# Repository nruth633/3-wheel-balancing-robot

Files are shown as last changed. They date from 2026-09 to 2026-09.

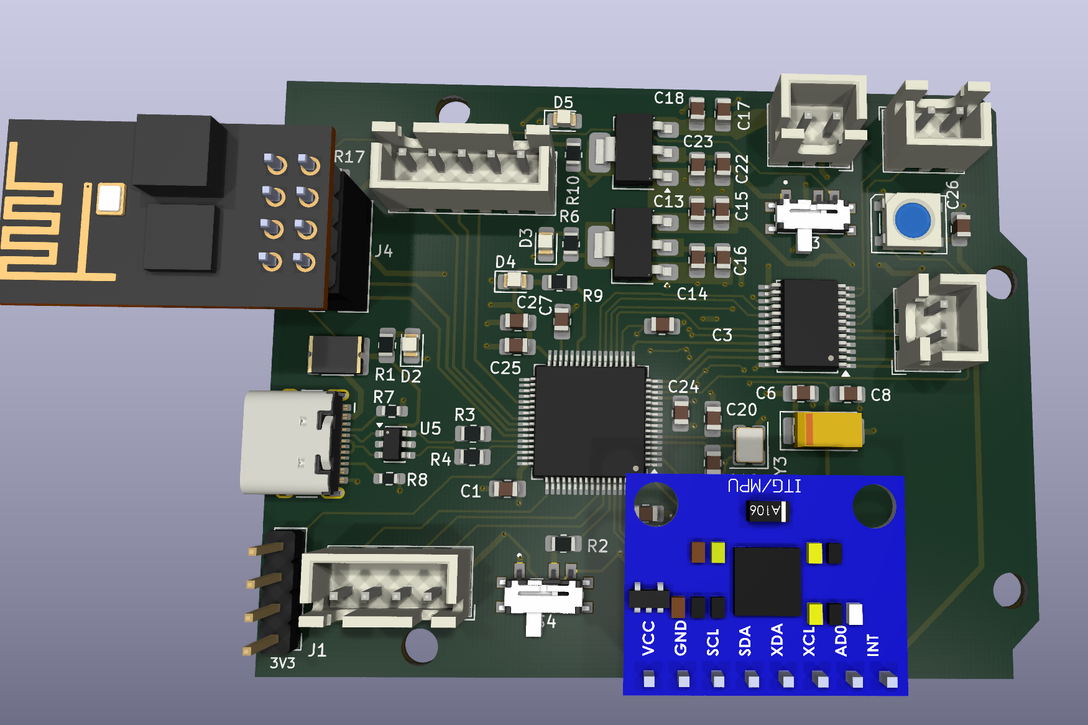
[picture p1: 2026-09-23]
firmware_main/Docs_Process/3D.png

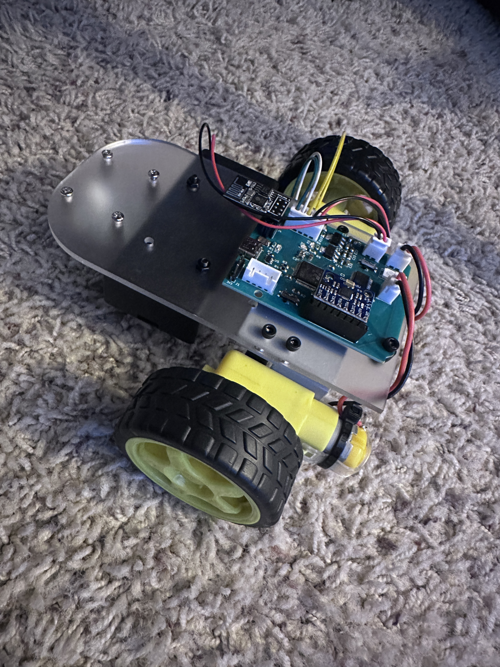
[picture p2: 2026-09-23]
firmware_main/Docs_Process/ROBOT_TOP.JPG

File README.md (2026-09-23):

# 3-Wheel Robot

A three-wheel robot on an STM32F401 control board I designed in KiCad and soldered by hand.
An ESP8266 runs its own WiFi access point and serves a control page, so you can drive it from
a phone browser. Button presses go over a WebSocket to the ESP8266, which passes them to the
STM32 over UART. Roll and pitch from the MPU6050 are sent back to the page. The STM32 firmware was provided
by my professor; I built it and flashed the board with STM32CubeIDE and STM32CubeProgrammer.

I started this as a self-balancing robot, but I didn't get as far as a working balance
controller, so for now it only drives. The wheel encoder code is also switched off, so the
speed readout on the control page stays at 0.

Write-up: https://nruth633.github.io/projects/balancing-robot.html

## What's in here

- `balance_noEncoder/`: the STM32 firmware (STM32CubeIDE, HAL). Reads the MPU6050 through a
  complementary filter at 100 Hz, drives the motors through a TB6612FNG, and talks to the
  ESP8266 over UART.
- `remote_esp8266/`: the ESP8266 sketch (access point, web page, WebSocket server).
- `pcb/`: KiCad project for the control board.
- `firmware_v2/`: KiCad project for a later board revision.
- `firmware_main/`: the first board, a two-wheel version: KiCad files, gerbers, an
  interactive BOM, a CAD model of the assembly, and build photos. No firmware, despite
  the name.

The board files were saved in KiCad 9 and 10, so open them in KiCad 10.

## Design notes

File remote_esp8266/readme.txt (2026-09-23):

Example 1 and 2
*********************
- Reference/intermediate code used to build ESP8266_KitchenTimer

ESP8266_KitchenTimer
*********************
- HTML being used inside ESP
- Open file and compress it using this link -> https://www.textfixer.com/html/compress-html-compression.php
- Copy the compress version and paste inside the message string arduino code.

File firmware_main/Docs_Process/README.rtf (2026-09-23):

-The PCB schematic and layout were designed in Kicad.
-Once manufactured I hand soldered the SMD components to the board and tested.
-The PCB was measured in Onshape so I could design a base
-The acrylic base was first drawn out in Onshape, printed on paper to ensure the parts would fit, and then it was sent to the CO2 laser cutter for manufacturing.
-Once the base was made, the PCB, batteries, motors, encoder, and wheels were attached to the base.
-The STM32 program provided by our professor, I used STM32CubeIDE and STM32CubeProgrammer to build, and flash the PCB.
-Once the program was on the board I tested it by connecting my phone to the ESP8266, and go to the ip address in a browser.
-Upon testing the robot works as intended. One issue I noticed was the ESP8266 app would sometimes disconnect, but would reconnect a few moments later.

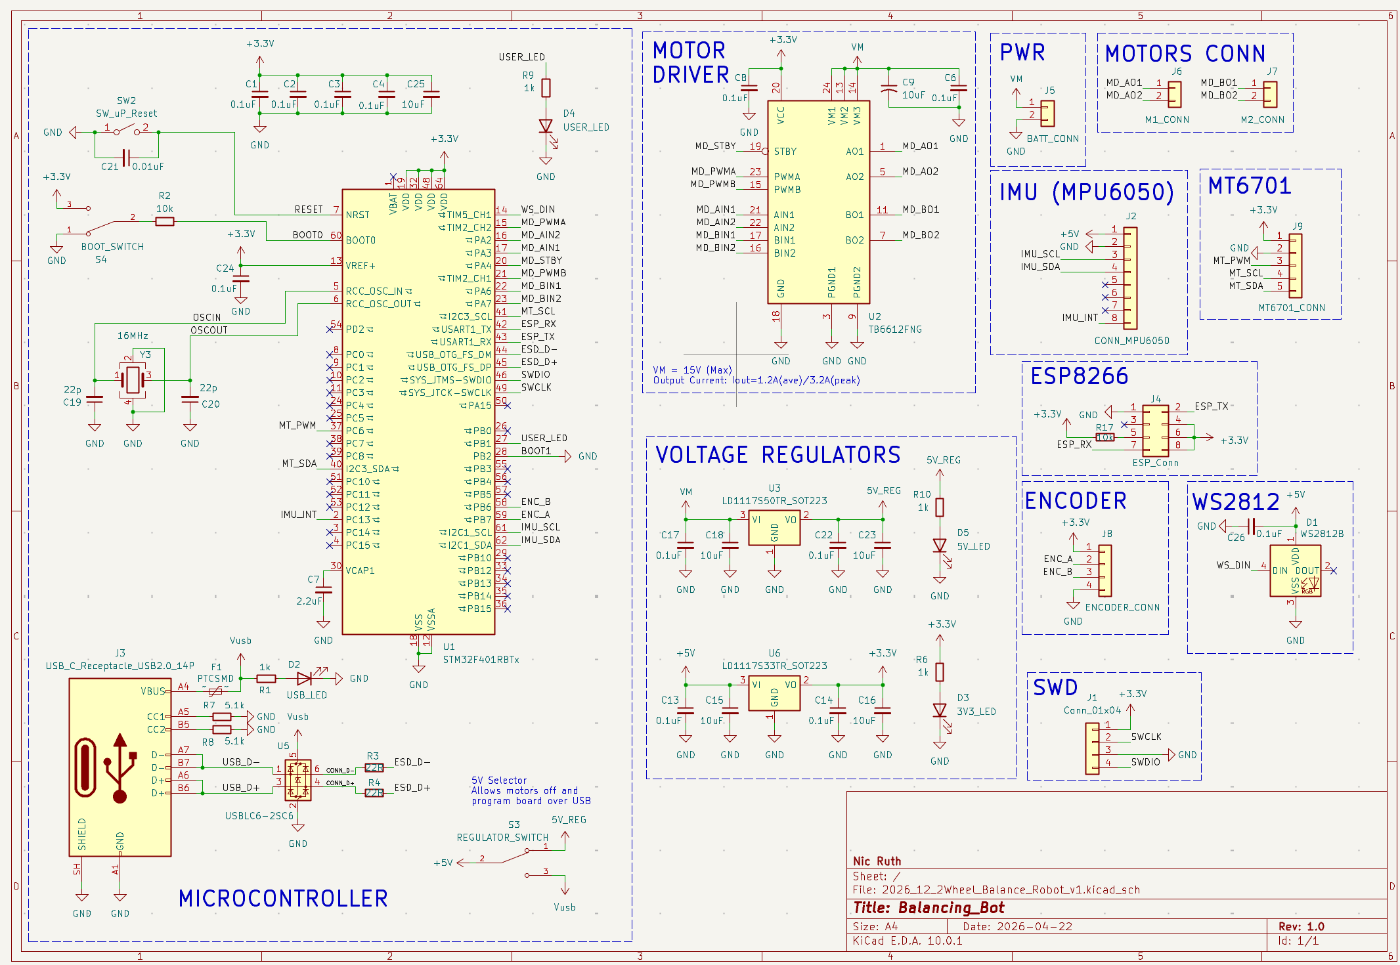
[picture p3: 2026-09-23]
firmware_main/Docs_Process/SCHEMATIC.png

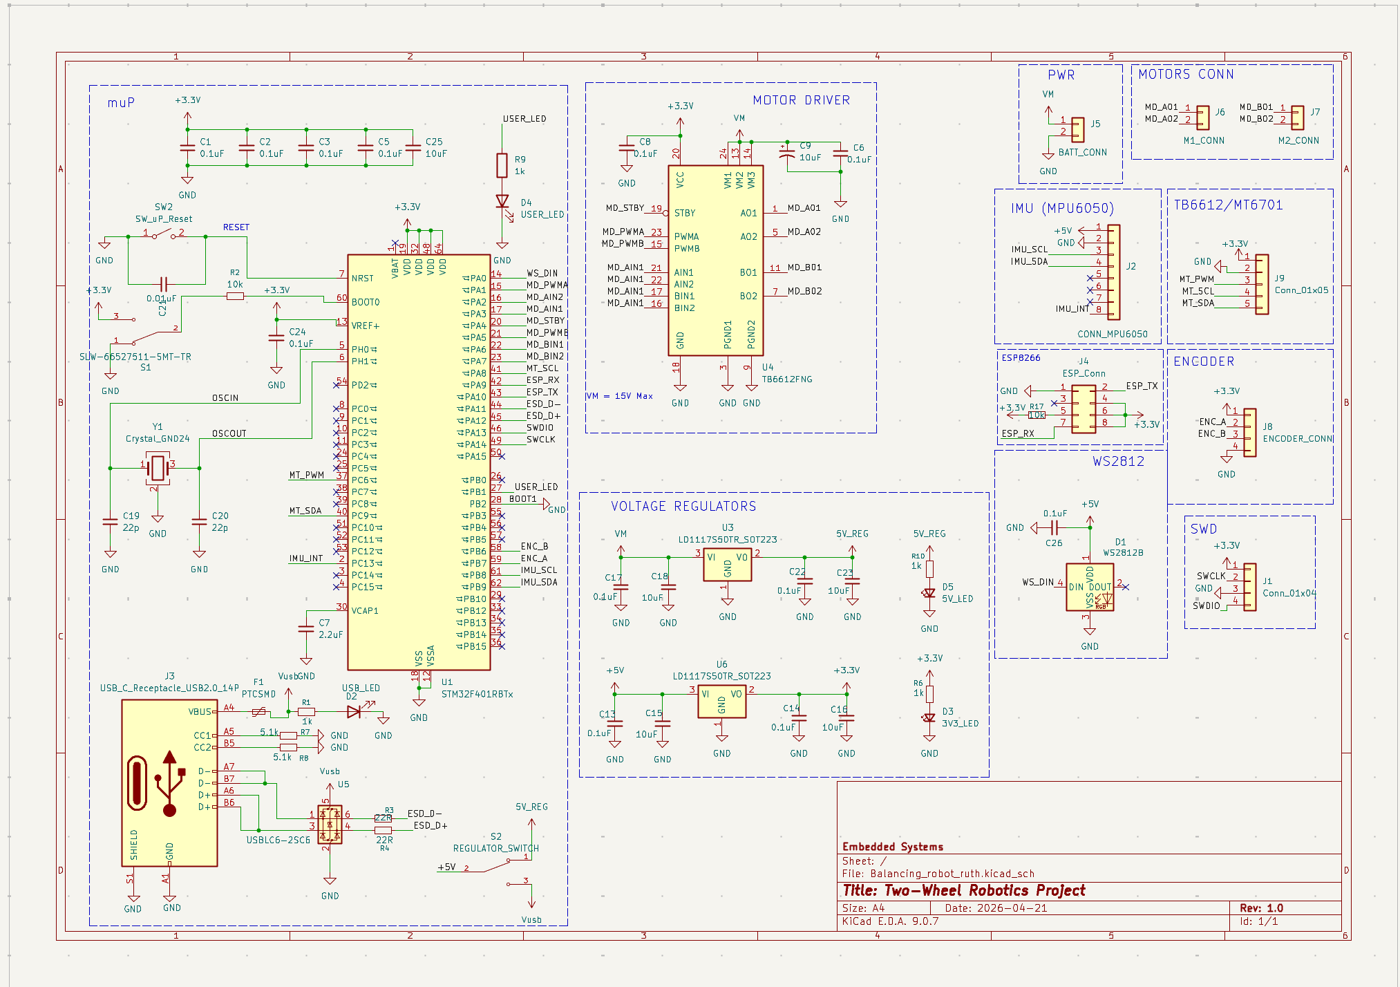
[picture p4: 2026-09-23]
pcb/docs/SCHEM.png

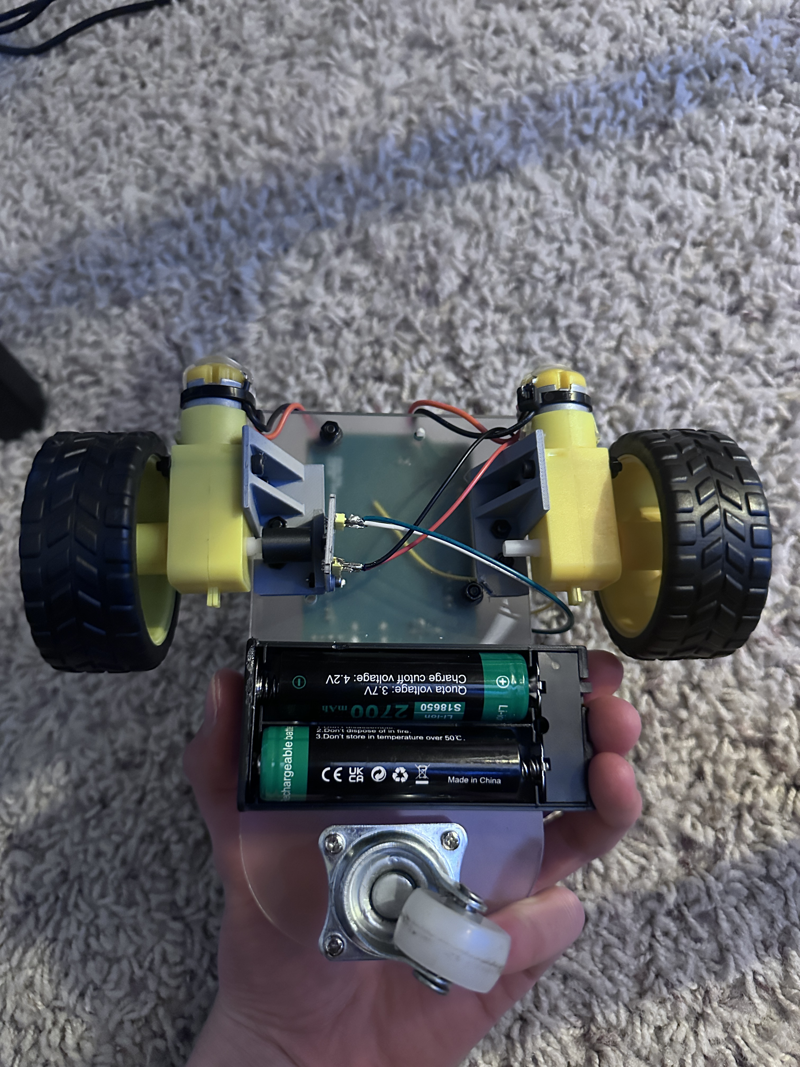
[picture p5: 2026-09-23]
firmware_main/Docs_Process/ROBOT_BOTTOM.JPG

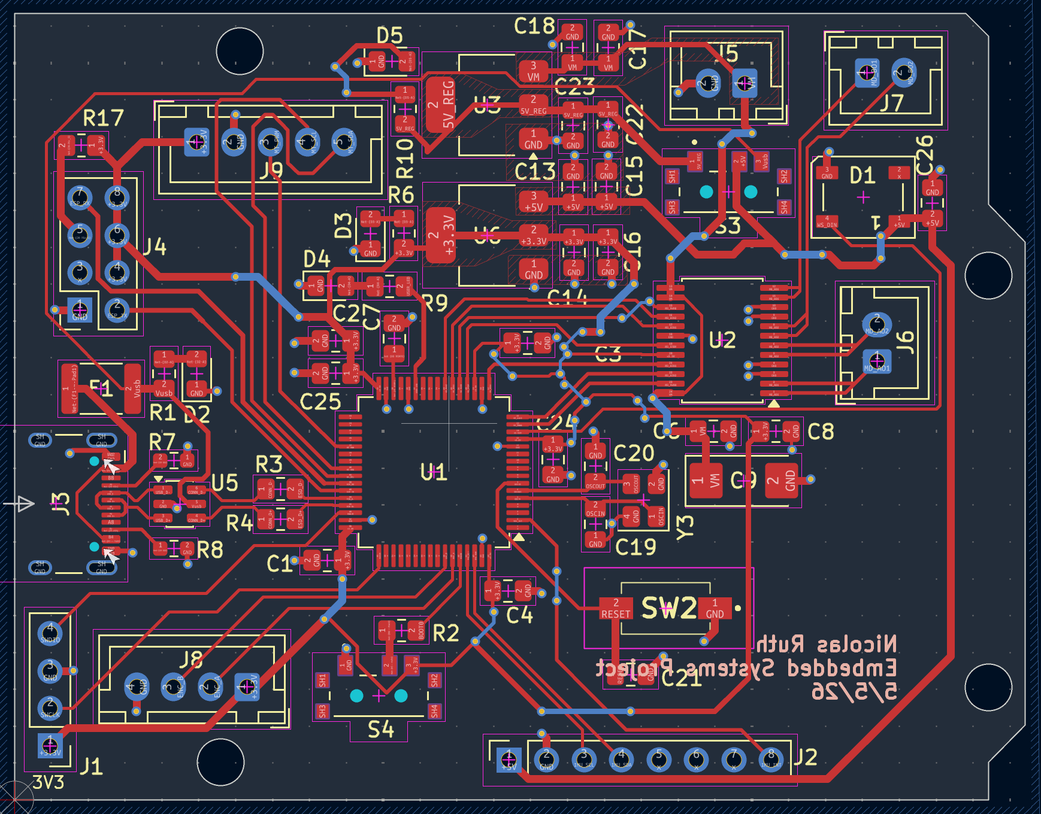
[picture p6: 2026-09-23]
firmware_main/Docs_Process/LAYOUT.png

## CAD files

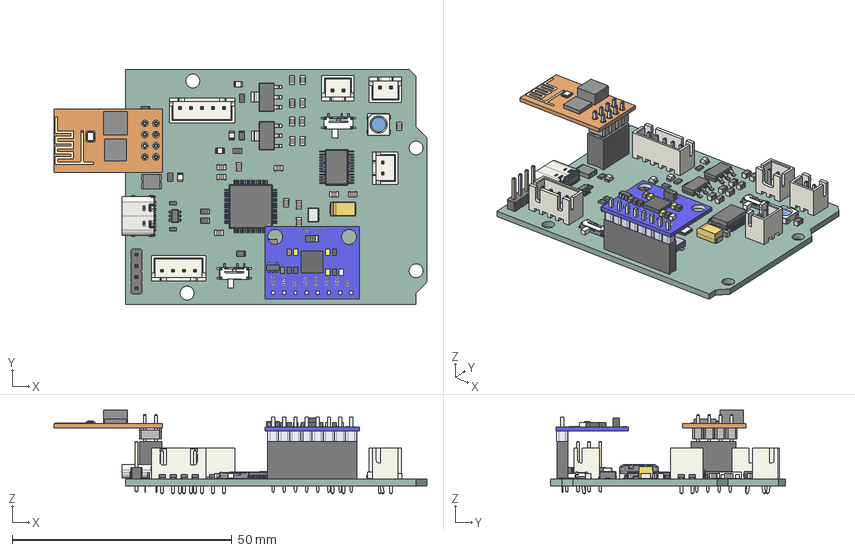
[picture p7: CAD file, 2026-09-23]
firmware_main/cad/robot_assembly.step
84.9 x 53.4 x 19.0 mm
C_0805_2012Metric x 21
MF-MSMF050-2--3DModel-STEP-56544
R_0805_2012Metric x 8
SOT-23-6
SOT-223 x 2
SLW-66527511-SMT-TR x 2
PinSocket_2x04_P2.54mm_Vertical
ESP8266-01_ESP-01
R_0603_1608Metric x 2
SSOP-24_5.3x8.2mm_P0.65mm
LED_WS2812B_PLCC4_5.0x5.0mm_P3.2mm
base
top cover
pins x 2
LQFP-64_10x10mm_P0.5mm
LED_0805_2012Metric x 4
Crystal_SMD_Abracon_ABM8G-4Pin_3.2x2.5mm
JST_XH_B2B-XH-A_1x02_P2.50mm_Vertical x 3
PinHeader_1x04_P2.54mm_Vertical
JST_XH_B5B-XH-A_1x05_P2.50mm_Vertical
USB_C_Receptacle_GCT_USB4105-xx-A_16P_TopMnt_Horizontal
PinSocket_1x08_P2.54mm_Vertical
8 Header-Pin
Placa_Base
CP_EIA-6032-28_Kemet-C
JST_XH_B4B-XH-A_1x04_P2.50mm_Vertical
2026_12_2Wheel_Balance_Robot_v1_PCB

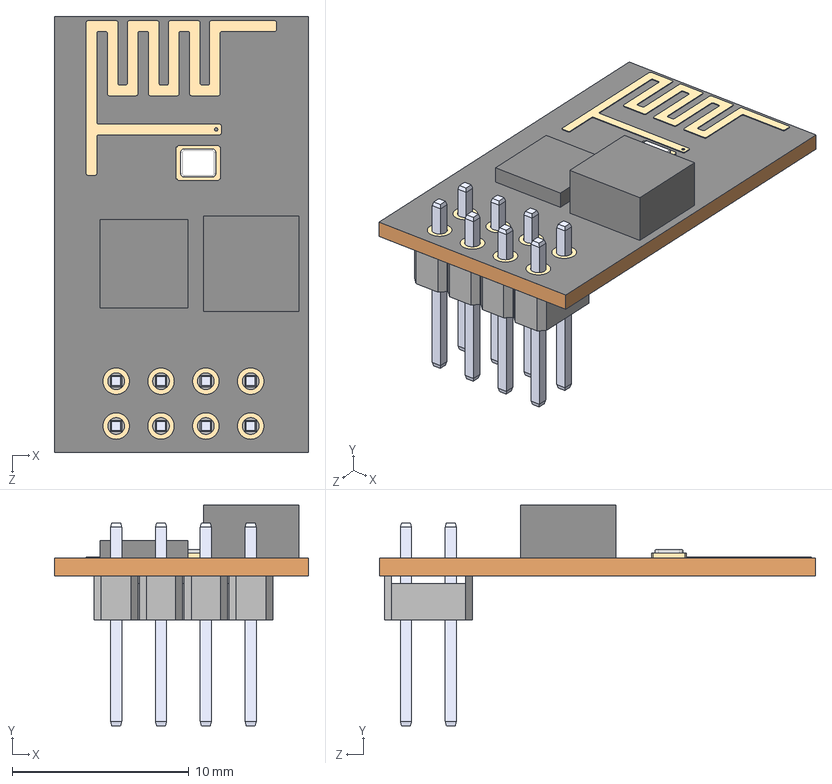
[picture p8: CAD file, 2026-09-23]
firmware_main/Components/ESP8266-01_ESP-01/step/ESP8266-01_ESP-01.step
14.4 x 12.5 x 24.7 mm

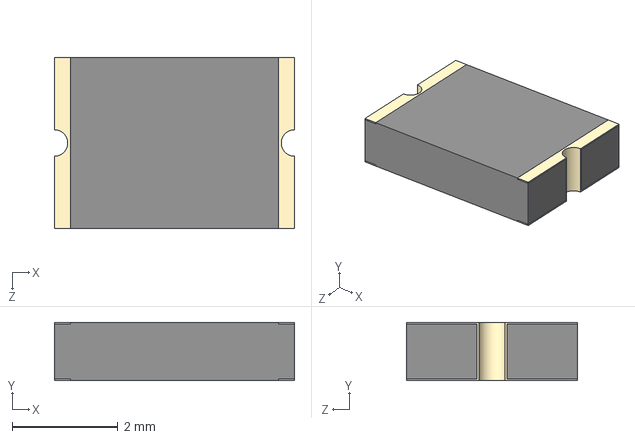
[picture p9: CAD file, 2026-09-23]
firmware_main/Components/Fuse_3DModel/MF-MSMF050-2--3DModel-STEP-56544.STEP
4.55 x 1.10 x 3.24 mm

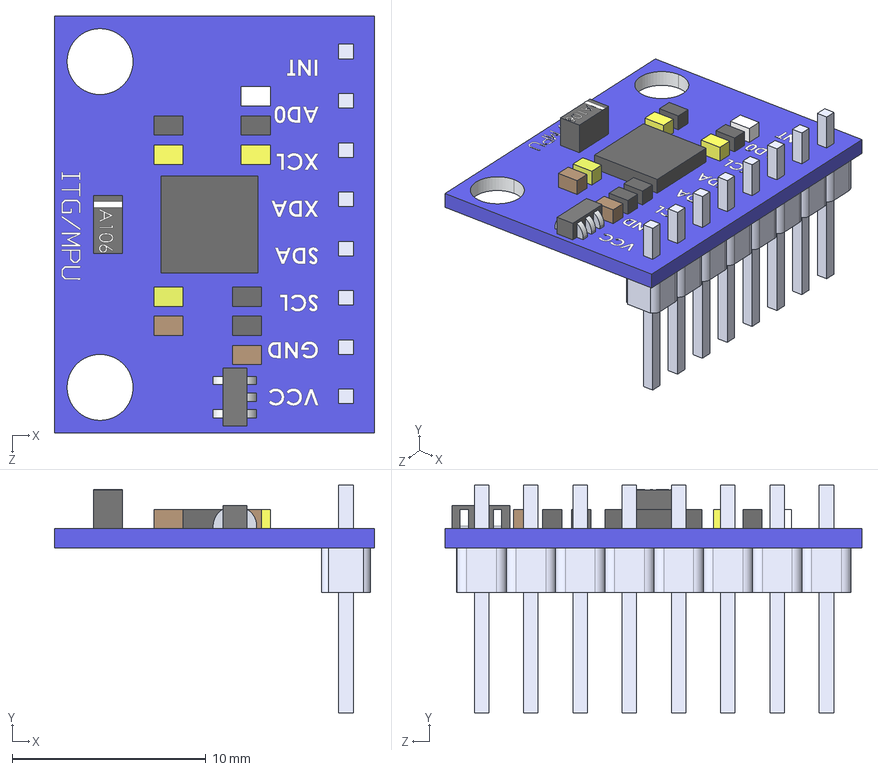
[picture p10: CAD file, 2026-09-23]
firmware_main/Components/MPU6050/ITG-MPU.STEP
16.5 x 11.8 x 21.5 mm
8 Header-Pin
Placa_Base

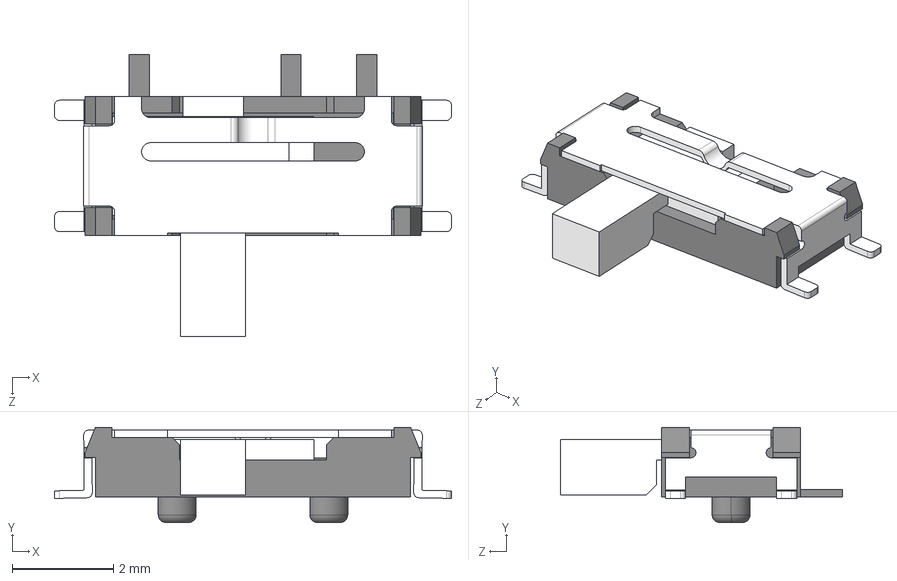
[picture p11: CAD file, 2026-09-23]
firmware_main/Components/SPDT_Slide_Switch/step/SLW-66527511-SMT-TR.step
7.86 x 1.88 x 5.58 mm

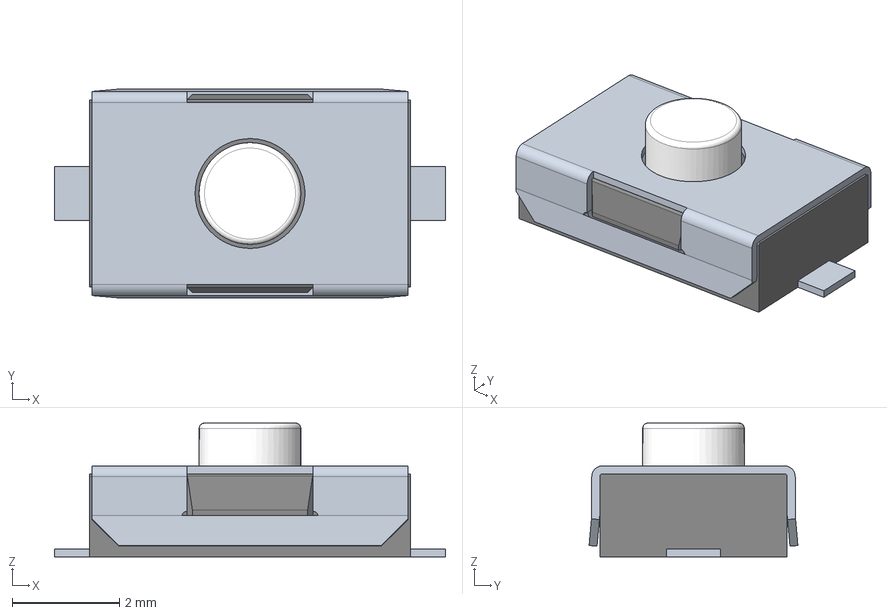
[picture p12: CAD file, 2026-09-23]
firmware_main/Components/SW_uP_Reset/step/SW_uP_Reset.stp
7.30 x 3.90 x 2.50 mm

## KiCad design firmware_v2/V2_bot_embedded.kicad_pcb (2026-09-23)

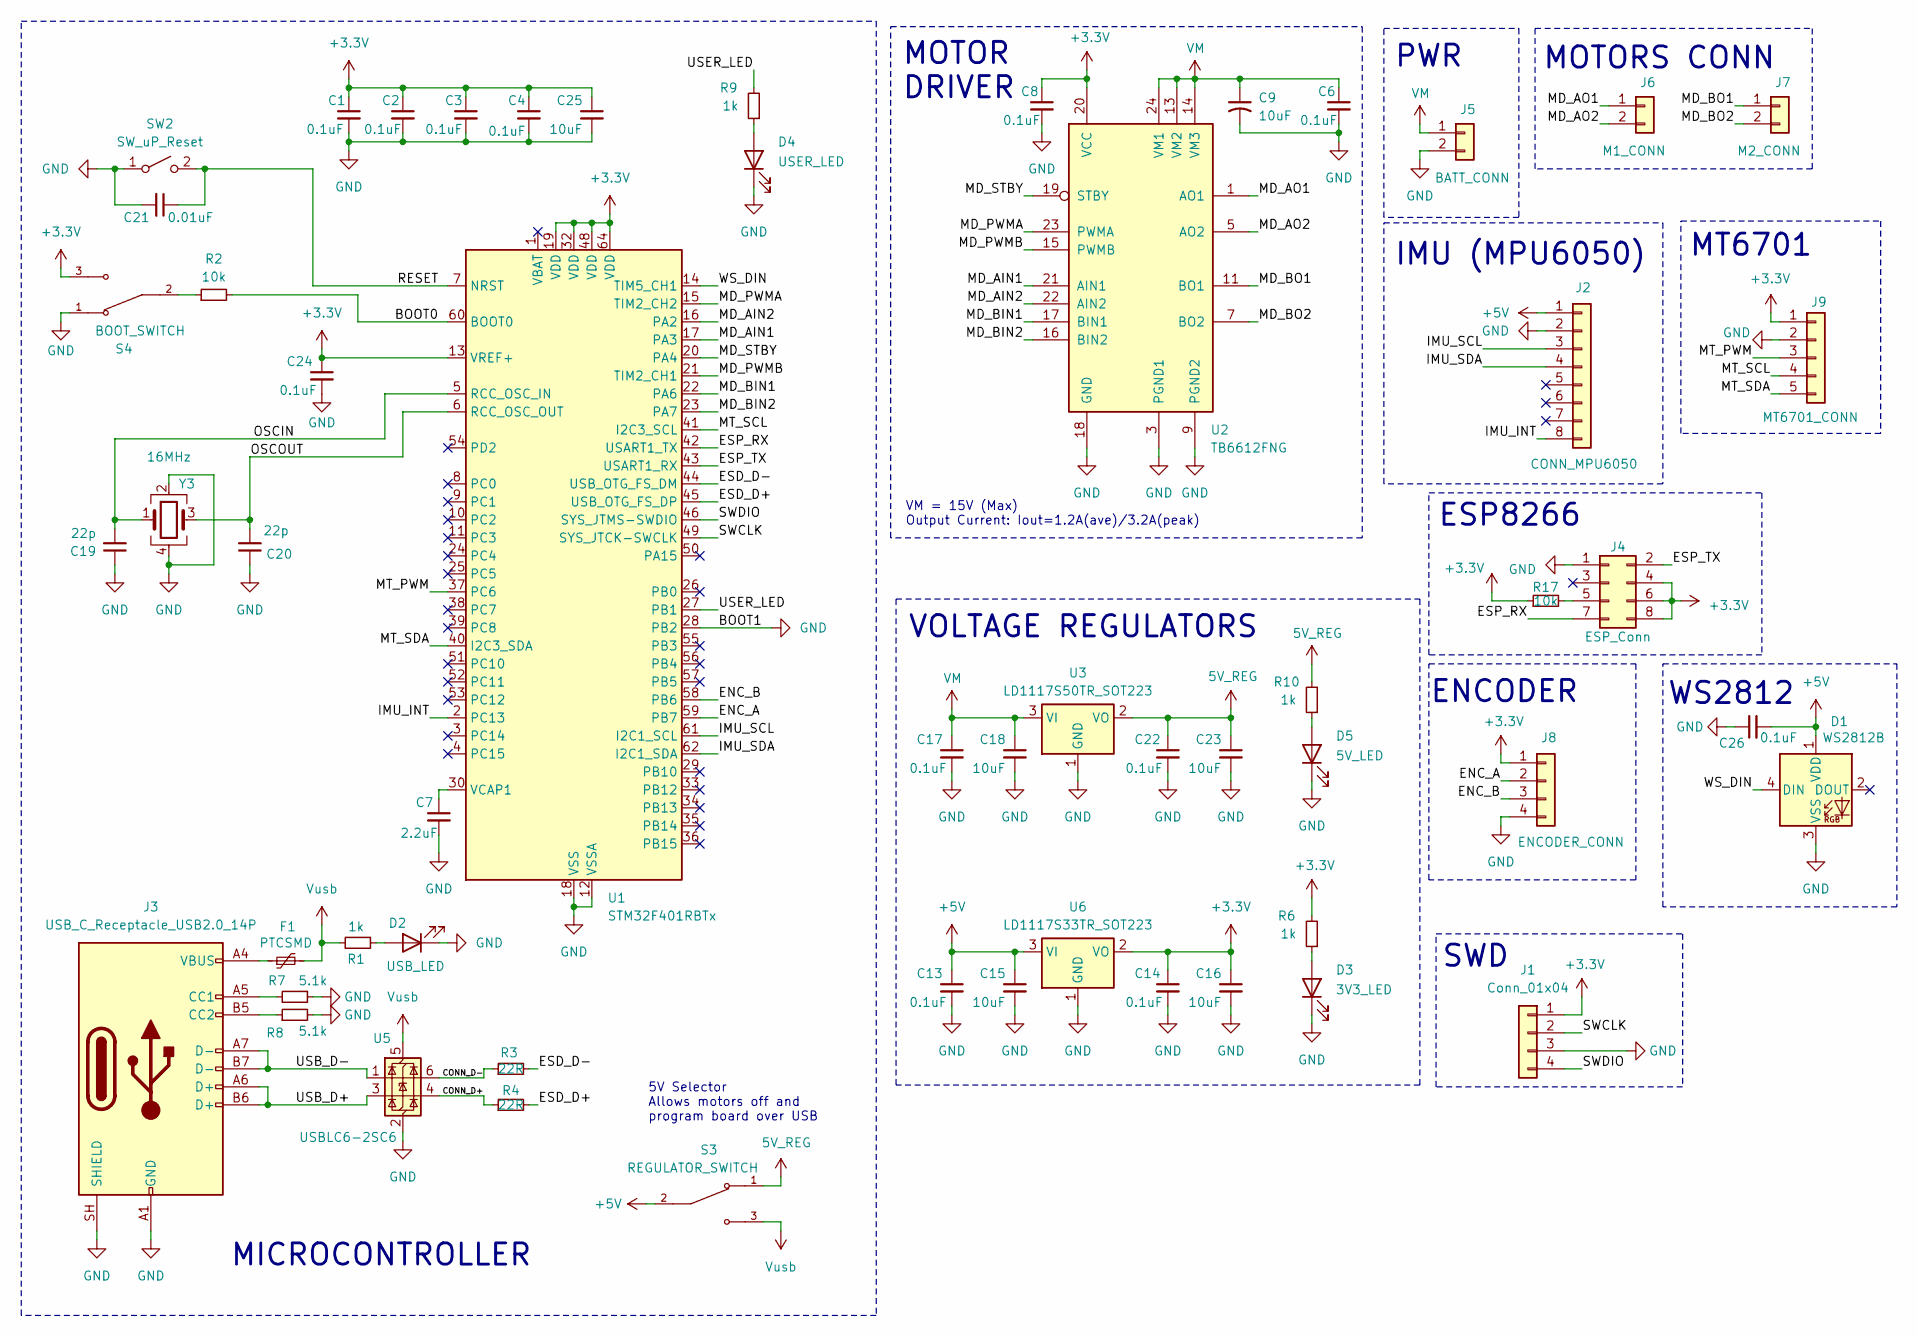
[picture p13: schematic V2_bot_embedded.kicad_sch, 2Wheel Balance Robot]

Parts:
C1, C2, C3, C4, C6, C8, C13, C14, C17, C22, C24, C26: 0.1uF; C_0805_2012Metric_Pad1.18x1.45mm_HandSolder; Mfr # C0805C104K4JACAUTO
C7: 2.2uF; C_0805_2012Metric_Pad1.18x1.45mm_HandSolder; Mfr # C0805X225K3RACAUTO
C9: 10uF; CP_EIA-6032-28_Kemet-C_HandSolder; Mfr # TPSC106M025R0500
C15, C16, C18, C23: 10uF; C_0805_2012Metric_Pad1.18x1.45mm_HandSolder; Mfr # C0805C106K4PACTU
C19, C20: 22p; C_0805_2012Metric_Pad1.18x1.45mm_HandSolder; Mfg Part# 08055C220KAT2A
C21: 0.01uF; C_0805_2012Metric_Pad1.18x1.45mm_HandSolder; Mfg Part# KAF21BR72A103JT
C25: 10uF; C_0805_2012Metric_Pad1.18x1.45mm_HandSolder; Mfg Part# C0805C106K4PACTU
D1: WS2812B; LED_WS2812B_PLCC4_5.0x5.0mm_P3.2mm; Mfr # FZ2812-5050; Mouser Digikey Part
D2: USB_LED; LED_0805_2012Metric_Pad1.15x1.40mm_HandSolder; Mfr # 150080BS75000
D3: 3V3_LED; LED_0805_2012Metric_Pad1.15x1.40mm_HandSolder; Mfr # 150080BS75000
D4: USER_LED; LED_0805_2012Metric_Pad1.15x1.40mm_HandSolder; Mfr # 150080BS75000
D5: 5V_LED; LED_0805_2012Metric_Pad1.15x1.40mm_HandSolder; Mfr # 150080BS75000
F1: PTCSMD; Fuse_1812_4532Metric; Mfr # MF-MSMF050-2
J1: Conn_01x04; PinHeader_1x04_P2.54mm_Vertical
J2: CONN_MPU6050; PinSocket_1x08_P2.54mm_Vertical
J3: USB_C_Receptacle_USB2.0_14P; USB_C_Receptacle_HCTL_HC-TYPE-C-16P-01A; Mfg Part# UJ20-C-H-C-4-SMT-TR
J4: ESP_Conn; PinSocket_2x04_P2.54mm_Vertical
J5: BATT_CONN; JST_XH_B2B-XH-A_1x02_P2.50mm_Vertical
J6: M1_CONN; JST_XH_B2B-XH-A_1x02_P2.50mm_Vertical
J7: M2_CONN; JST_XH_B2B-XH-A_1x02_P2.50mm_Vertical
J8: ENCODER_CONN; JST_XH_B4B-XH-A_1x04_P2.50mm_Vertical
J9: MT6701_CONN; JST_XH_B5B-XH-A_1x05_P2.50mm_Vertical
R1, R6, R9, R10: 1k; R_0805_2012Metric_Pad1.20x1.40mm_HandSolder; Mfr # TNPW08051K00FEEA
R2, R17: 10k; R_0805_2012Metric_Pad1.20x1.40mm_HandSolder; Mfr # CPF0805B10KE1
R3, R4: 22R; R_0805_2012Metric_Pad1.20x1.40mm_HandSolder; Mfr # RCA080522R0FKEA
R7, R8: 5.1k; R_0603_1608Metric_Pad0.98x0.95mm_HandSolder; Mfg Part# CRCW06035K10FKEC
S3: REGULATOR_SWITCH; SW_SLW-66527511-SMT-TR; PARTREV 1.01
S4: BOOT_SWITCH; SW_SLW-66527511-SMT-TR; PARTREV 1.01
SW2: SW_uP_Reset; Mfg Part# 434121025816
U1: STM32F401RBTx; LQFP-64_10x10mm_P0.5mm; Mfr # STM32F401RBT6
U2: TB6612FNG; SSOP-24_5.3x8.2mm_P0.65mm; Mfr # TB6612FNG,C,8,EL
U3: LD1117S50TR_SOT223; SOT-223-3_TabPin2; Mfr # LD1117S50TR
U5: USBLC6-2SC6; SOT-23-6; Mfr # USBLC6-2SC6
U6: LD1117S33TR_SOT223; SOT-223-3_TabPin2; Mfr # LD1117S33TR
Y3: 16MHz; Crystal_SMD_Abracon_ABM8G-4Pin_3.2x2.5mm; Mfg Part# ABM8-16.000MHZ-D1X-T

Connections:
5V_REG: C22.1, C23.1, R10.2, S3.1, U3.2 (VO)
+3.3V: C1.1, C2.1, C3.1, C4.1, C8.1, C14.1, C16.1, C24.1, C25.1, J1.1, J4.4, J4.6, J4.8, J8.1, J9.1, R6.2, R17.1, S4.3, U1.13 (VREF+), U1.19 (VDD), U1.32 (VDD), U1.48 (VDD), U1.64 (VDD), U2.20 (VCC), U6.2 (VO)
+5V: C13.1, C15.1, C26.2, D1.1 (VDD), J2.1, S3.2, U6.3 (VI)
/BOOT0: R2.2, U1.60 (BOOT0)
/CONN_D+: R4.1, U5.4 (I/O2)
/CONN_D-: R3.1, U5.6 (I/O1)
/ENC_A: J8.2, U1.59 (PB7)
/ENC_B: J8.3, U1.58 (PB6)
/ESD_D+: R4.2, U1.45 (USB_OTG_FS_DP)
/ESD_D-: R3.2, U1.44 (USB_OTG_FS_DM)
/ESP_RX: J4.7, U1.42 (USART1_TX)
/ESP_TX: J4.2, U1.43 (USART1_RX)
/IMU_INT: J2.8, U1.2 (PC13)
/IMU_SCL: J2.3, U1.61 (I2C1_SCL)
/IMU_SDA: J2.4, U1.62 (I2C1_SDA)
/MD_AIN1: U1.17 (PA3), U2.21 (AIN1)
/MD_AIN2: U1.16 (PA2), U2.22 (AIN2)
/MD_AO1: J6.1, U2.1 (AO1), U2.2 (AO1)
/MD_AO2: J6.2, U2.5 (AO2), U2.6 (AO2)
/MD_BIN1: U1.22 (PA6), U2.17 (BIN1)
/MD_BIN2: U1.23 (PA7), U2.16 (BIN2)
/MD_BO1: J7.1, U2.11 (BO1), U2.12 (BO1)
/MD_BO2: J7.2, U2.7 (BO2), U2.8 (BO2)
/MD_PWMA: U1.15 (TIM2_CH2), U2.23 (PWMA)
/MD_PWMB: U1.21 (TIM2_CH1), U2.15 (PWMB)
/MD_STBY: U1.20 (PA4), U2.19 (STBY)
/MT_PWM: J9.3, U1.37 (PC6)
/MT_SCL: J9.4, U1.41 (I2C3_SCL)
/MT_SDA: J9.5, U1.40 (I2C3_SDA)
/OSCIN: C19.2, U1.5 (RCC_OSC_IN), Y3.1
/OSCOUT: C20.2, U1.6 (RCC_OSC_OUT), Y3.3
/RESET: C21.1, SW2.2 (B), U1.7 (NRST)
/SWCLK: J1.2, U1.49 (SYS_JTCK-SWCLK)
/SWDIO: J1.4, U1.46 (SYS_JTMS-SWDIO)
/USB_D+: J3.A6 (D+), J3.B6 (D+), U5.3 (I/O2)
/USB_D-: J3.A7 (D-), J3.B7 (D-), U5.1 (I/O1)
/USER_LED: R9.2, U1.27 (PB1)
/WS_DIN: D1.4 (DIN), U1.14 (TIM5_CH1)
GND: C1.2, C2.2, C3.2, C4.2, C6.2, C7.2, C8.2, C9.2, C13.2, C14.2, C15.2, C16.2, C17.2, C18.2, C19.1, C20.1, C21.2, C22.2, C23.2, C24.2, C25.2, C26.1, D1.3 (VSS), D2.1 (K), D3.1 (K), D4.1 (K), D5.1 (K), J1.3, J2.2, J3.A1 (GND), J3.A12 (GND), J3.B1 (GND), J3.B12 (GND), J3.SH (SHIELD), J4.1, J5.2, J8.4, J9.2, R7.1, R8.2, S4.1, SW2.1 (A), U1.12 (VSSA), U1.18 (VSS), U1.28 (PB2), U1.31 (VSS), U1.47 (VSS), U1.63 (VSS), U2.3 (PGND1), U2.4 (PGND1), U2.9 (PGND2), U2.10 (PGND2), U2.18 (GND), U3.1 (GND), U5.2 (GND), U6.1 (GND), Y3.2, Y3.4
unnamed: D2.2 (A), R1.1
unnamed: D3.2 (A), R6.1
unnamed: D4.2 (A), R9.1
unnamed: D5.2 (A), R10.1
unnamed: F1.1, J3.A4 (VBUS), J3.A9 (VBUS), J3.B4 (VBUS), J3.B9 (VBUS)
unnamed: J3.A5 (CC1), R7.2
unnamed: J3.B5 (CC2), R8.1
unnamed: J4.5, R17.2
unnamed: R2.1, S4.2
unnamed: C7.1, U1.30 (VCAP1)
VM: C6.1, C9.1, C17.1, C18.1, J5.1, U2.13 (VM2), U2.14 (VM3), U2.24 (VM1), U3.3 (VI)
Vusb: F1.2, R1.2, S3.3, U5.5 (VBUS)

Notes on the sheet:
5V Selector Allows motors off and program board over USB
MT6701
SWD
MOTORS CONN
IMU (MPU6050)
MOTOR DRIVER
VOLTAGE REGULATORS
ENCODER
MICROCONTROLLER
PWR
ESP8266
VM = 15V (Max) Output Current: Iout=1.2A(ave)/3.2A(peak)
WS2812

Board: 2 copper layers, 56 parts (0 on the bottom side), 51 nets, no tracks yet.

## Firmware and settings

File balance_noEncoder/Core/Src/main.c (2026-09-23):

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
/* Includes ------------------------------------------------------------------*/
#include "main.h"

/* USER CODE BEGIN Includes */
#include <stdio.h>  // snprintf

#include "ENGREDU_WS2812.h"
#include "TJ_MPU6050.h"
#include "ENGREDU_TB6612.h"
//#include "ENGREDU_MT6701.h"
/* USER CODE END Includes */

I2C_HandleTypeDef hi2c1;
I2C_HandleTypeDef hi2c3;

TIM_HandleTypeDef htim2;
TIM_HandleTypeDef htim3;
TIM_HandleTypeDef htim4;
TIM_HandleTypeDef htim5;
DMA_HandleTypeDef hdma_tim5_ch1;

UART_HandleTypeDef huart1;

PCD_HandleTypeDef hpcd_USB_OTG_FS;

/* USER CODE BEGIN PV */

uint8_t gTMP = 0;

// Simple Scheduler
uint32_t last_led_tick        = 0; // Timestamp of the last LED toggle for blinking
uint32_t last_telemetry_tick  = 0; // Timestamp of the last telemetry transmission for periodic updates

// UART
uint8_t uart_rx_byte; // Buffer for receiving a single byte over UART
volatile uint8_t gUART_Cmd;

char gTelemetry[64];

// MPU6050 + complementary filter
CompFilter_Def gCompFilter;
uint32_t last_imu_tick = 0;

// TB6612

TB6612_Motor gMotorA = {
		.htim = &htim2, // timer for PWM
		.Channel = TIM_CHANNEL_2,
		.IN1_Port = AIN1_GPIO_Port,
		.IN1_Pin = AIN1_Pin,
		.IN2_Port = AIN2_GPIO_Port,
		.IN2_Pin = AIN2_Pin,
		.STBY_Port = STANDBY_GPIO_Port,
		.STBY_Pin = STANDBY_Pin,
		.Offset = 1
};

TB6612_Motor gMotorB = {
		.htim = &htim2, // timer for PWM
		.Channel = TIM_CHANNEL_1,
		.IN1_Port = BIN1_GPIO_Port,
		.IN1_Pin = BIN1_Pin,
		.IN2_Port = BIN2_GPIO_Port,
		.IN2_Pin = BIN2_Pin,
		.STBY_Port = STANDBY_GPIO_Port,
		.STBY_Pin = STANDBY_Pin,
		.Offset = 1
};

// MT6701
//MT6701_Handle encoder;

/* USER CODE END PV */

void SystemClock_Config(void);
static void MX_GPIO_Init(void);
static void MX_DMA_Init(void);
static void MX_I2C1_Init(void);
static void MX_I2C3_Init(void);
static void MX_TIM4_Init(void);
static void MX_TIM5_Init(void);
static void MX_USART1_UART_Init(void);
static void MX_USB_OTG_FS_PCD_Init(void);
static void MX_TIM2_Init(void);
static void MX_TIM3_Init(void);
/**
  * @brief  The application entry point.
  * @retval int
  */
int main(void)
{

  /* USER CODE BEGIN 1 */
	MPU_ConfigTypeDef myMpuConfig;
  /* USER CODE END 1 */

  /* MCU Configuration--------------------------------------------------------*/

  /* Reset of all peripherals, Initializes the Flash interface and the Systick. */
  HAL_Init();

  /* Configure the system clock */
  SystemClock_Config();

  /* Initialize all configured peripherals */
  MX_GPIO_Init();
  MX_DMA_Init();
  MX_I2C1_Init();
  MX_I2C3_Init();
  MX_TIM4_Init();
  MX_TIM5_Init();
  MX_USART1_UART_Init();
  MX_USB_OTG_FS_PCD_Init();
  MX_TIM2_Init();
  MX_TIM3_Init();
  /* USER CODE BEGIN 2 */

  //1. Initialize the MPU6050 module and I2C1
  MPU6050_Init(&hi2c1);
  //2. Configure Accel and Gyro parameters
  myMpuConfig.Accel_Full_Scale = AFS_SEL_4g;
  myMpuConfig.ClockSource = Internal_8MHz;
  myMpuConfig.CONFIG_DLPF = DLPF_184A_188G_Hz;
  myMpuConfig.Gyro_Full_Scale = FS_SEL_500;
  myMpuConfig.Sleep_Mode_Bit = 0;  //1: sleep mode, 0: normal mode
  MPU6050_Config(&myMpuConfig);
  HAL_Delay(50); // gyro needs ~30 ms to stabilize after power-on
  MPU6050_CompFilter_Init(&gCompFilter, 0.995f);

  // Initialize WS2812 LED strip with TIM5 and set pixel color
  WS2812_Init(&htim5);
  WS2812_SetPixel(30, 30, 30);

  // Start UART reception in interrupt mode for 1 byte
  HAL_UART_Receive_IT(&huart1, &uart_rx_byte, 1);

  // Initialize Motors
  TB6612_Init(&gMotorA);  // the other motor (left)
  TB6612_Init(&gMotorB);  // motor with encoder (right)

  TB6612_Brake(&gMotorA);
  TB6612_Brake(&gMotorB);

  // Initialize Encoder
  //1. Initialize MT6701 with I2C3
  //MT6701_Init(&encoder, &hi2c3);
  //MT6701_SetZero(&encoder);
  //2. Initialize Timer 3 for Encoder
  //HAL_TIM_Base_Start_IT(&htim3);

  /* USER CODE END 2 */

  /* Infinite loop */
  /* USER CODE BEGIN WHILE */
  while (1)
  {
	  // TODO
	  uint32_t now = HAL_GetTick(); // Get the current system tick in milliseconds

	  // Toggle the user LED every 100 ms for a blinking effect
	  if (now - last_led_tick >= 100)
	  {
		  last_led_tick = now;
		  HAL_GPIO_TogglePin(USER_LED_GPIO_Port, USER_LED_Pin);
	  }

	  // Read IMU and run complementary filter at 100 Hz (10 ms)
	  if (now - last_imu_tick >= 10)
	  {
		  float dt = (now - last_imu_tick) * 0.001f;
		  last_imu_tick = now;
		  MPU6050_CompFilter_Update(&gCompFilter, dt);
	  }

	  // Send telemetry data every 100 ms
	  if (now - last_telemetry_tick >= 100)
	  {
		  last_telemetry_tick = now;

	      float speed = 0.0;//encoder.velocity_deg_s;  /* encoder-derived wheel speed */
	      float roll  = gCompFilter.roll;  /* side angle */
	      int16_t pitch = gCompFilter.pitch;  /* front angle */
	      int16_t counter = gTMP;  /* counter */

	      int len = snprintf(gTelemetry, sizeof(gTelemetry),
	                         "$%.2f,%.2f,%d,%d\r\n",
	                         speed, roll, pitch, counter);
	      HAL_UART_Transmit_IT(&huart1, (uint8_t *)gTelemetry, len);

	      gTMP = (gTMP + 1) % 20;
	  }

      if (gUART_Cmd != 0)
      {
          switch (gUART_Cmd)
          {
              case 'w':
            	  WS2812_SetPixel(30, 0, 0);
            	  TB6612_Drive(&gMotorA, 30);
            	  TB6612_Drive(&gMotorB, 30);
            	  break;

              case 's':
            	  WS2812_SetPixel(0, 30, 0);
            	  TB6612_Drive(&gMotorA, -30);
            	  TB6612_Drive(&gMotorB, -30);
            	  break;

              case 'a':
            	  WS2812_SetPixel(0, 0, 30);
            	  TB6612_Drive(&gMotorA, 30);
            	  TB6612_Brake(&gMotorB);
            	  break;

              case 'd':
            	  WS2812_SetPixel(30, 30, 0);
            	  TB6612_Brake(&gMotorA);
            	  TB6612_Drive(&gMotorB, 30);
            	  break;

              case 'x':
            	  WS2812_SetPixel(0, 0, 0);
            	  TB6612_Brake(&gMotorA);
            	  TB6612_Brake(&gMotorB);
            	  break;
          }
          gUART_Cmd = 0;
      }

    /* USER CODE END WHILE */

    /* USER CODE BEGIN 3 */
  }
  /* USER CODE END 3 */
}

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
/* USER CODE BEGIN 4 */

// TODO
void HAL_TIM_PWM_PulseFinishedCallback(TIM_HandleTypeDef *htim)
{
    HAL_TIM_PWM_Stop_DMA(htim, TIM_CHANNEL_1);  // WS2812 DMA -> Timer5
}

// UART receive complete callback function to control the robot based on received byte
void HAL_UART_RxCpltCallback(UART_HandleTypeDef *huart)
{
    if (huart->Instance == USART1)
    {
    	gUART_Cmd = uart_rx_byte;
        HAL_UART_Receive_IT(&huart1, &uart_rx_byte, 1);
    }
}

// Re-arm RX IT after any UART error (e.g. overrun) so reception never dies
void HAL_UART_ErrorCallback(UART_HandleTypeDef *huart)
{
    if (huart->Instance == USART1)
    {
        HAL_UART_Receive_IT(&huart1, &uart_rx_byte, 1);
    }
}

void HAL_TIM_PeriodElapsedCallback(TIM_HandleTypeDef *htim){
	if(htim->Instance == TIM3){
		// Update Encoder
		//float dt = 0.1f;  // 10Hz
		//MT6701_Update(&encoder, dt);
	}
}

/* USER CODE END 4 */
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

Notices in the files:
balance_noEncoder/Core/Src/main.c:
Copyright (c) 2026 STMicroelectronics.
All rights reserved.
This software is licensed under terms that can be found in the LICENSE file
